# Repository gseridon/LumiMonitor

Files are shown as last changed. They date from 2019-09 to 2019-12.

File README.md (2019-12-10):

# Si7021 Temperature and Humidity Module
# Build Instructions
-----

## Author: Gino Seridon

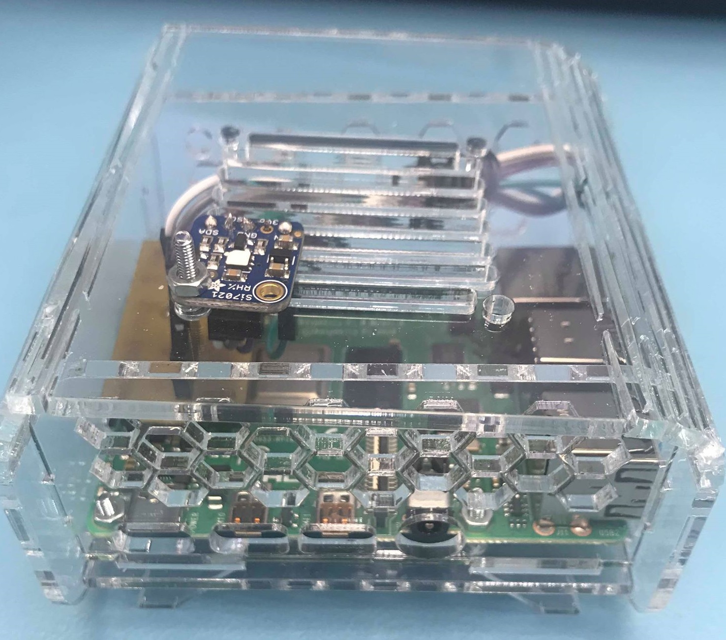
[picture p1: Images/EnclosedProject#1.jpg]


## Table of Contents
-----

1. [Introduction](https://github.com/gseridon/LumiMonitor#Introduction)
2. [Specifications](https://github.com/gseridon/LumiMonitor#Specifications)
3. [Design](https://github.com/gseridon/LumiMonitor#Design)
4. [Acquisition](https://github.com/gseridon/LumiMonitor#Acquisition)
5. [Assembly](https://github.com/gseridon/LumiMonitor#Assembly)
6. [Testing and Power Up](https://github.com/gseridon/LumiMonitor#Testing-and-Power-Up)
7. [Production Testing](https://github.com/gseridon/LumiMonitor#Production-Testing)

-----

## Introduction

-----

This readme will allow the user to build and assemble a functioning temperature and humidity reader using the si7021 sensor in conjunction with the Raspberry Pi 4.

The document will cover all points of the build, from the materials, budget and time commitment, to the mechanical assembly, testing, and power up. It will also cover all the problems that was encountered during the project, steps to take to prevent them from occurring, as well as highlighting steps that may cause problems in the future. 

While the project was completed over a 13-week semester, following this build instruction should allow the user to have an assembled and functional module within 4 hours, given that the required materials and components have already been ordered and ready to be used. 

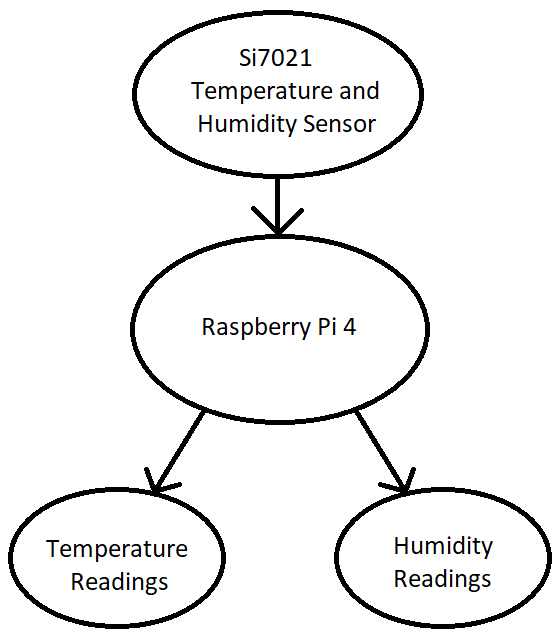
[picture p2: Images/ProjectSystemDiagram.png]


The system diagram above visualizes how the Si7021 Temperature and Humidity sensor retrieves data and interacts with the Raspberry Pi 4 to process the readings of the sensors.

-----

## Specifications

-----

A complete list of all parts, components, tools, and materials needed for this project will be listed below. Assuming that the user does not own the components, this will be the breakdown of the budget (in Canadian dollars, before shipping):

| Component | Price (CAD) |
| --- | --- |
| [Si7021 Temperature and Humidity Sensor Breakout Board](https://tinyurl.com/yybwv9qn) | $12.86 |
| [CanaKit Raspberry Pi 4 Starter Kit (4GB RAM)](https://tinyurl.com/vg57wxr) | $134.99 |
| [Printed Circuit Board (PCB)](https://www.seeedstudio.com/free-assembly-for-5-pcbs.html) | $5.21 ($3.92 USD) |
| [Clear Acrylic Casing](https://www.protocase.com/design/send-your-cad.php) | $35.00 |
| [Headers for the PCB ](https://tinyurl.com/ufy8mfr) | $21.99 |
| [Jumper Wires](https://tinyurl.com/unpvbn7) | $15.99 |
| [22 Gauge Insulated Wires](https://tinyurl.com/wlea6bo) | $18.99 |
| [Ethernet Cable](https://tinyurl.com/sbod2cs) | $8.29 |
| [Ethernet-USB Adapter](https://tinyurl.com/tccs4yx) | $20.05 |
| [Nuts and Bolts Kit](https://tinyurl.com/vyvv2pt) | $31.98 |
| **Total** | **$305.25** |

With these items, the cost will be **$305.25 + $39.70** in tax, totaling to **$344.93.** The Ethernet Cable and Ethernet-USB Adapter are optional, as the user will be able to connect their Raspberry Pi to a computer monitor if it has an HDMI port. If the monitor does not have an HDMI port, then the user must use the cable and adapter. The cost will be reduced depending on which items the user already has in possession.

The total cost of the budget will vary depending on the shipping cost, but it should be around the same price range. Considering that the Printed Circuit Board and Acrylic Casing has been obtained from Humber College, the price used for the PCB and the casing will be an accurate estimate.

The cost of shipping is not included as it can vary depending on different factors, such as the address on where the products will be shipped, the shipping method, and membership discounts/free shipping perks. 

-----

## Design

-----

The design files are important for the project, as they will dictate the appearance of the printed circuit board and the casing. The design of the printed circuit board is simplistic, as there are only four (4) pins used by the si7021 sensor and therefore the connections made from the sensor the RP4 are straightforward.

The creation and the design of the PCB is done using the free software <a href="https://fritzing.org/home/">“Fritzing.”</a> This program will provide a <a href="https://raw.githubusercontent.com/gseridon/LumiMonitor/master/Images/BreadboardV1.png">breadboard view</a> of the connections, a <a href="https://raw.githubusercontent.com/gseridon/LumiMonitor/master/Images/SchematicV1.png">schematic</a>, as well as a view of the <a href="https://raw.githubusercontent.com/gseridon/LumiMonitor/master/Images/PCBV1.png">printed circuit board</a>. There are two Fritzing files used: one to display the breadboard and the schematic, and another for the designed PCB (this will be the file used when creating the PCB).

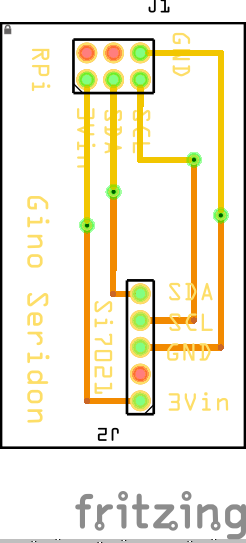
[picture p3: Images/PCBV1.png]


The design is simplistic and neat in order to reduce complications. The files can be tweaked for personal customization, but they are perfectly useable in terms of functionality. There were very little problems when designing the PCB, however, be mindful of the VIA hole size, as it may cause problems when finding a suitable size wire. Obtaining this component will be described later on in the Acquisition Section.

The enclosure is a design that was retrieved <a href="https://www.thingiverse.com/thing:3729316">online</a>. It uses cover design that allows the acrylic to bend over the raspberry pi, with several ventilation holes to help regulate the heat of the RP4.

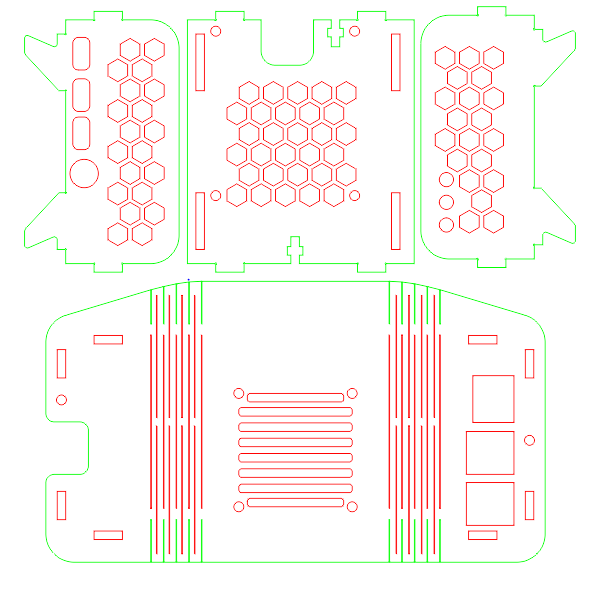
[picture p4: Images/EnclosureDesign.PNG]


The <a href="https://github.com/gseridon/LumiMonitor/blob/master/Mechanical/Raspberry_Pi_4_Model_B_Retro_Case_-_All_Parts_v2.0.cdr">design file</a> can be accessed and edited using the program “CorelDRAW”, which offers a 15-day trial for new users. 

Obtaining this component will be described in the Acquisition Section.

-----

## Acquisition

-----

The parts and components needed for this project is listed in the specification. They can be found online, and links are also provided in the specifications section. Allow a couple of days for delivery, depending on the shipping type used to deliver the parts.

Acquiring the PCB and the enclosure will require a bit more time, as they must be custom made based on the design files submitted. It takes around 4-5 business days to process the custom request and to have it delivered to a specified address. Plan ahead of time when it comes to this, as this will be the biggest cause of delays should there be problems down the line, especially when getting it replaced.

**The Printed Circuit Board**
-----

The PCB design will be sent to Seeedstudio, a company that can manufacture circuit boards. The company requests that the Gerber Files of the project be sent as ZIP or RAR files in order to proceed with the PCB manufacturing. 

To create an order with <a href="https://www.seeedstudio.com/free-assembly-for-5-pcbs.html">Seeedstudio</a>:

\-   Open the <a href="https://github.com/gseridon/LumiMonitor/blob/master/Electronics/GinoSeridon_TemperatureHumiditySensorWithoutPiV2.fzz">PCB Design File</a> in Fritzing

\-   Export the file as an Extended Gerber 

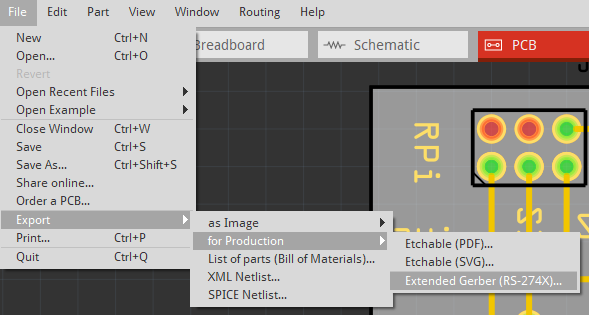
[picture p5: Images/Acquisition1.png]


\-   Select a folder to export the files into

\-   Compress the folder into a ZIP or RAR file

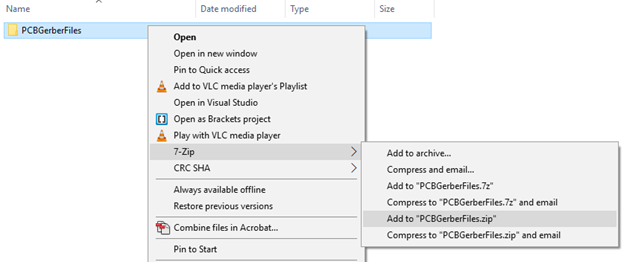
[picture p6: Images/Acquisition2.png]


\-   File is created

\-   Upload this newly created ZIP or RAR file on the Seeedstudio website and follow the steps online.

Note that if some of the PCB specifications are changed, the price will also change accordingly. The site will provide an estimate on how long it will take for the PCB to be manufactured and when it will arrive.

**The Enclosure**
-----

The enclosure design will be sent to Protocase, a company that can manufacture cases and enclosures, among other services. To request for a custom design enclosure, we must export the CorelDRAW file as a .dwg file. This file is uploaded into the repository and it will be used to place the order for the enclosure.

To order from Protocase:

\-   Access the website’s <a href="https://www.protocase.com/design/send-your-cad.php">page</a> for custom enclosure orders

\-   Send the design by selecting “Upload your file using request a quote form”

\-   Select “I have 3D CAD file(s) to upload”

\-   Upload the .dwg file

\-   Select “Part(s) or Enclosure(s) from other materials” for the type of enclosure

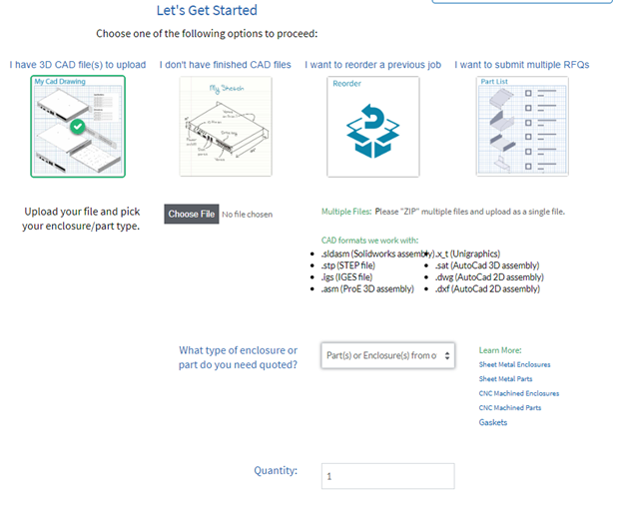
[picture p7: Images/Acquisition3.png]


\-   Select the Material type as “Acrylic”, with a thickness of “ 0.118’’ | 3.0mm”

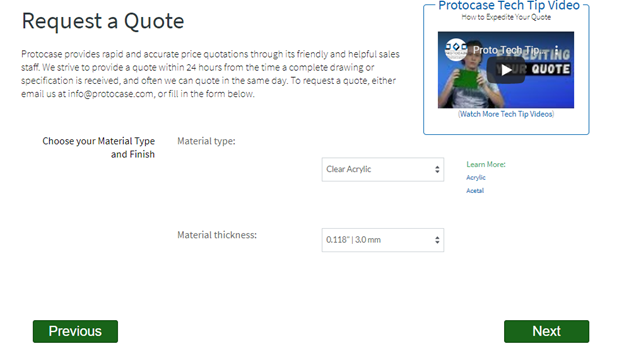
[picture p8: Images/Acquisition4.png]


\-   Fill out the rest of the form with personal information and submit

\-   Wait for an email from Protocase; this will contain the quote on the enclosure

\-   Follow the email and steps for ordering the case.

Awaiting the PCB and the enclosure will take around a week, so keep that in mind when setting deadlines.

**Tools and Software**
-----

Lastly, on top of the parts, components, and materials needed for the project, there are also some tools required to setup and assemble the project. These tools include:

\-   Windows PC

\-   computer monitor (preferably with an HDMI port; if not, then an Ethernet cable and Ethernet-USB adapter is required)

\-   computer mouse

\-   computer keyboard

\-   ohmmeter

\-   solder iron and lead

\-   wire stripper

\-   wire cutter

\-   breadboard

\-   Phillips Screwdriver

Software programs needed include:

\-   <a href="https://fritzing.org/home/">Fritzing</a>

\-   <a href="https://www.coreldraw.com/en/pages/ppc/coreldraw/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">CorelDRAW</a>

\-   <a href="https://www.balena.io/etcher/">balenaEtcher</a>

-----

## Assembly

-----

Once the components, tools, and materials have been acquired, the project can be assembled.

**Installing Raspbian onto the Rasberry Pi 4:**
-----

The Raspberry Pi must first be setup. On a running Windows Computer, download “Raspbian Buster with desktop and recommended software” from the <a href=” https://www.raspberrypi.org/downloads/raspbian/”>Raspberry Pi Website</a>. When that has completed, insert the microSD card into the USB reader (both from the Raspberry Pi Starter Kit) and then plug it in a USB port on the computer.

Launch balenaEtcher to mount the Raspbian into the microSD card. In balenaEtcher, select Raspbian as the Image, select the USB reader as the drive, and then click “Flash!” Wait for the Flashing and Validating to finish, and then safely eject the USB reader and leave it aside for the meantime.

Proceed by connecting the Raspberry Pi 4 to a mouse to its USB port, a keyboard to the other USB port, and its power supply to the microUSB port. The RP4 comes with its own HDMI cable, and it will be connect to the Pi’s HDMI port to a monitor’s HDMI port.

Place the microSD card in the microSD reader of the Raspberry Pi 4, then power up the Raspberry Pi using the power supply’s power button. The Operating System that was Flashed into the microSD card will automatically be installed on to the new Raspberry Pi. Follow the setup instructions that appear on the screen (and remember any password changes that are made), and the Raspberry Pi will be ready for future use. This section should not take more than half an hour, depending on download speed and processing speed.

**Si7021 Sensor/Header Soldering:**
-----

The Si7021 Temperature and Humidity Sensor should come with its own header. Since the header will not fit on the breakout board initially, use wire cutter so that there will only be 5 pins left on the header. The header will fit perfectly on the board, and the pins should then be soldered. Soldering the 3V pin is optional, as it will not be used. This should take no more than 10 minutes.

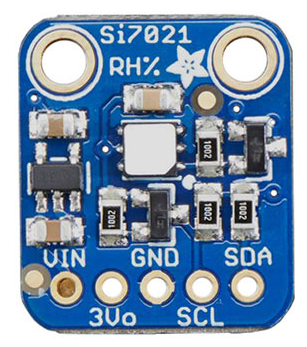
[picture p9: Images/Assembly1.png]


**Soldering Headers and VIAs on the Printed Circuit Board:**
-----

Headers must be soldered on the printed circuit board in order to connect the raspberry pi and the sensor to it. There will be two headers needed for this: 1x5 header, and 2x3 header.

First, the 1x5 header will be soldered first. This header will be placed on the topside of the PCB, with the pins being soldered at the bottom side (for reference, the student name and pin names will be on the topside of the PCB). When the header is placed on the topside, turn over the PCB and proceed with soldering the pins to the board. Ensure that the solders are clean and that they do not make contact with other pins on the board. The pins to be soldered are GND, SCL, SDA, and 3vin (the labels can be found on the topside of the PCB); the lone pin without any connections does not need to be soldered.

The second header will then be soldered afterwards. This header will be placed on the bottom side of the PCB, with the pins being solder at the topside of the board. Place the header on the bottom side of the PCB, then turn over the PCB to proceed with soldering the pins. There will be two pins that do not need to be soldered, and it will be the two pins that do not have any connections or labels attached to them. The four pins that will be soldered are the GND, SCL, SDA, and 3Vin.

Finally, when both headers are soldered to the board, the VIAs will be soldered using the 22 gauge insulated wires (these will be thin enough that they will be able to fit through the VIAs). Use the wire stripper to remove the insulation, and fit the wire through the VIA. One end of the wire will be soldered, ensuring that the solder is making contact with the copper wiring on the board. After one end is finished, cut the other end of the wire on the opposite end of the soldered VIA. The remaining insulation is removed from the wire, and then the wire end is soldered to the copper around the VIA. The end result should look like a wire soldered on both ends that is passing through the VIA. Proceed to do these steps until all 4 of the VIAs are connected.

Try to make sure that the solder points are done quickly and neatly. If soldered for too long, some areas of the board may overheat and become unusable, which may cause problems down the line. Do not use too much solder, as it may melt over to neighbouring wires, causing a short in the circuit. Do not rush soldering, but it should not take longer than an hour for this section.

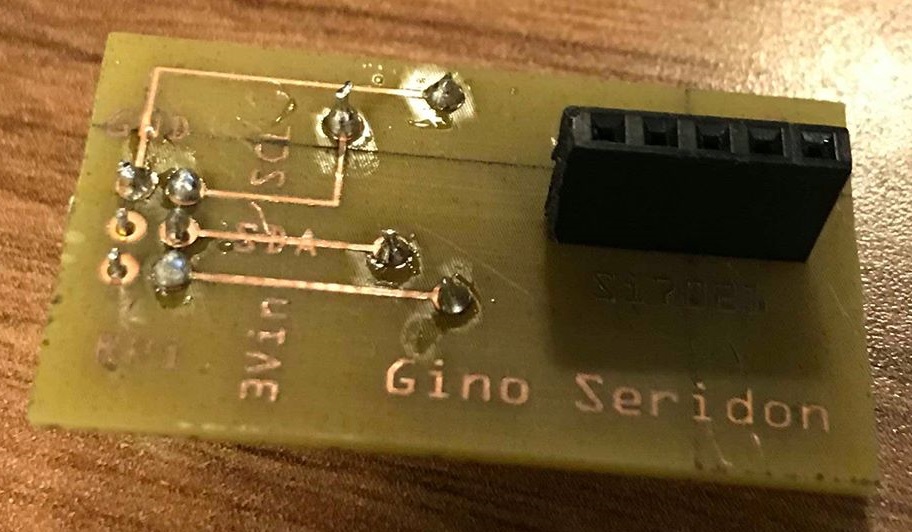
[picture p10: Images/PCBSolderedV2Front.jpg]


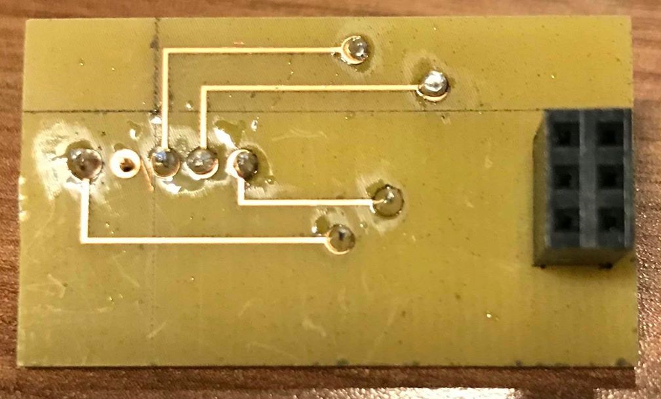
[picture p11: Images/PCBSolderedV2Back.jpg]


**Assembling the Enclosure with the Raspberry Pi:**
-----

**Note: Due to the nature of the enclosure, it is highly recommended that the Raspberry Pi 4, the Printed Circuit Board, and the Si7021 Temperature and Humidity Sensor are all configured, tested, and are fully functional before assembling them with the enclosure.

The enclosure is comprised of four pieces, the two side pieces, the bottom piece, and the large, overhead piece. Start by placing the raspberry pi on the bottom piece, aligning the case’s mounting holes with the Raspberry Pi’s. Secure the raspberry pi to the bottom piece using nuts and bolts.

Based on the orientation of the Raspberry Pi, the two side pieces of the enclosure should be attached to the bottom enclosure piece with accordance to the Raspberry Pi’s ports (one of the side pieces will have holes for the RP4’s ports, while the other does not). Use this knowledge to determine which side piece will fit with the bottom enclosure piece.

Attach the printed circuit board to the raspberry pi’s pins (the first 6 pins at the top of the pi, as seen on the breadboard connection), as well as four jumper wires on the proper pins of the circuit board (one for GND, SCL, SDA, and 3Vin).

Closing the case using the overhead piece is the trickiest part of using this case. Start on the end with the microSD card reader of the RP4. Fit the top piece of the enclosure to the bottom piece where the microSD card hole will be, and then use a single nut and bolt to hold and secure the two pieces together.

Slip the four jumper wires through the top slit near a mounting hole of the overhead piece. Connect these four jumper wires to the Si7021 sensor while keeping in mind the proper GND, SCL, SDA, and 3Vin pins. When the wires are connected, move the sensor so that it is resting on top of the case, and the breakout board’s mounting hole aligns with the mounting hole on the case. Use a nut and bolt to secure the sensor’s position. Afterwards, carefully bend the casing until it encloses the entire raspberry pi, and that it will connect to the bottom case piece on the other side. This side will also have another mounting hole to hold the case in its place using a nut and bolt. This part should take around half an hour, assuming the user takes their time and handles the components with care.

**The final result:**

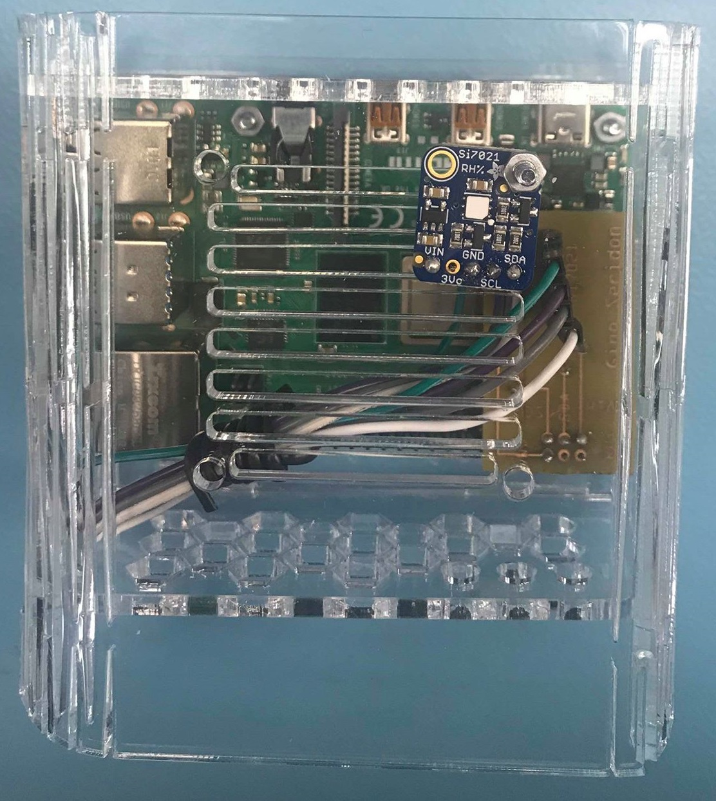
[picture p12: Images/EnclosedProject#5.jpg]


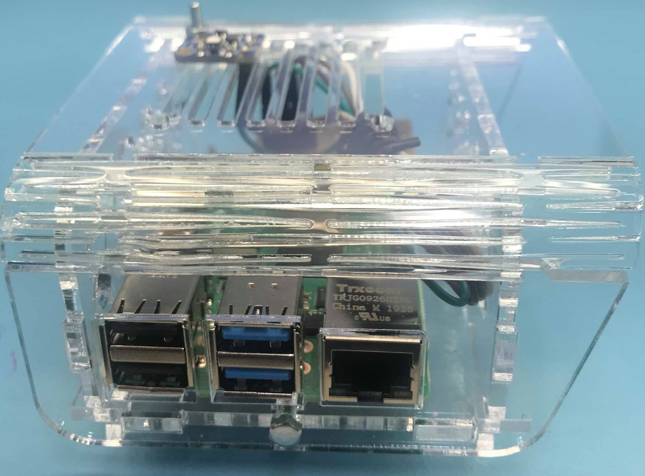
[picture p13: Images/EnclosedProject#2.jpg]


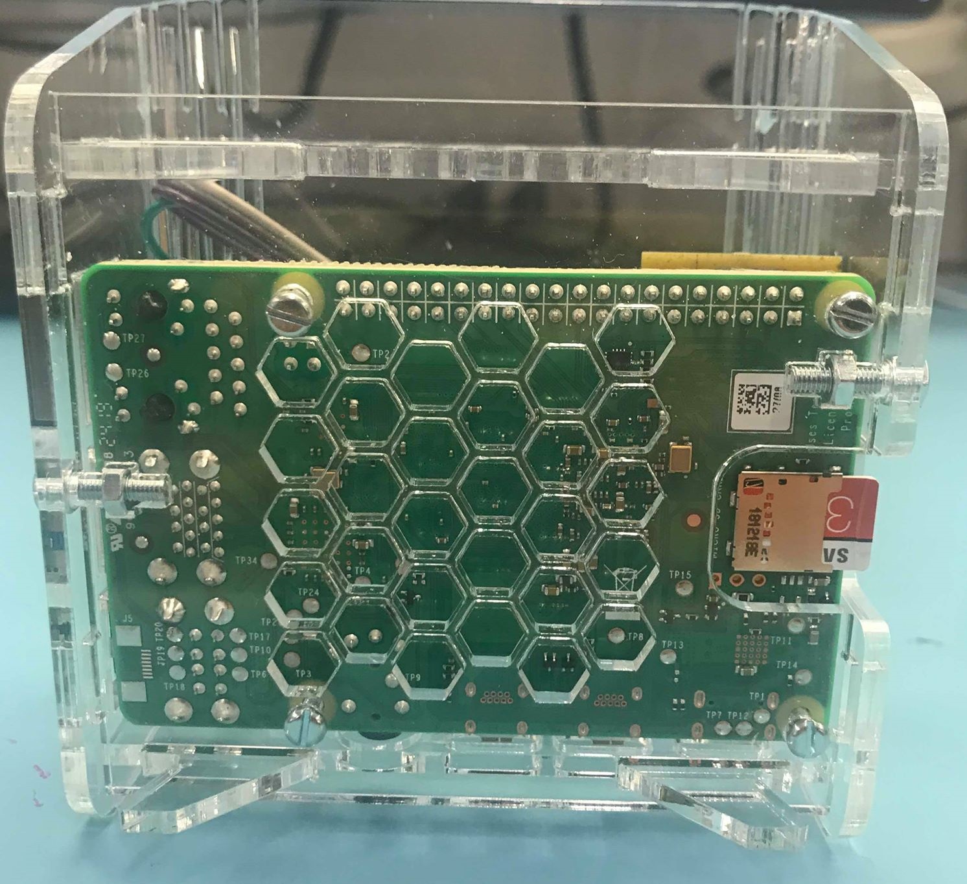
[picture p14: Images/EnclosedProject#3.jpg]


-----

## Testing and Power Up

-----

**Note: Due to the nature of the enclosure, it is highly recommended that the Raspberry Pi 4, the Printed Circuit Board, and the Si7021 Temperature and Humidity Sensor are all configured, tested, and are fully functional before assembling them with the enclosure.

Before testing the Raspberry Pi, the sensor and printed circuit board must be tested. It is simple enough to test: the soldered connections will be tested using an ohmmeter and some jumper wires. The sensor and printed circuit board can be plugged in a breadboard to make the connections clearer and easier to trace. Connect the PCB and sensor to the proper pins using jumper wires, connect it to a power supply, and then measure the resistance in the circuit. If the ohmmeter is reading an infinite resistance, it means that there is no electrical current flowing through the circuit that is being measured. If this is the case, look over the soldered pins and VIAs and ensure that the soldered points appear like a sloping hill, or a "Hershey Kiss".

Once it is verified that the PCB and sensor are soldered properly, the next step is to ensure that the Raspberry Pi is up to date with its libraries. Use the following commands from the command line to update the raspberry pi:

```
sudo apt-get install upgrade

sudo apt-get install update

sudo apt-get install i2c-tools
```

Once that’s done, run this command to install the Adafruit library:

```
sudo pip3 install adafruit-circuitpython-si7021
```
 
Then we need to enable the I2C bus on the Pi.

\-   Run sudo raspi-config

\-   Select Interfacing Options

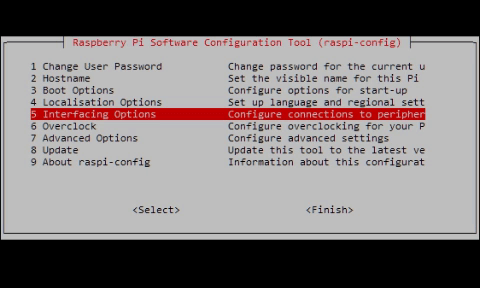
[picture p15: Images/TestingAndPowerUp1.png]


\-   Select P4 SPI

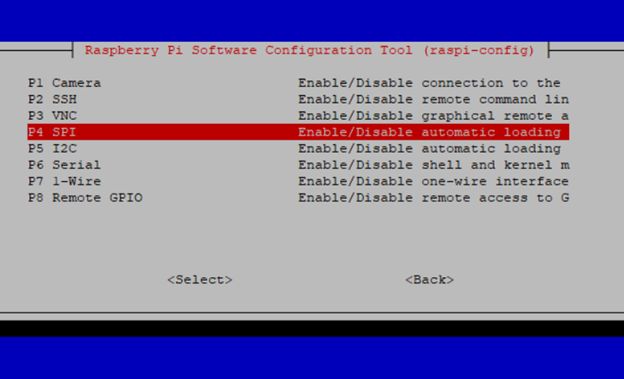
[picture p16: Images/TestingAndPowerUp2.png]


\-   Select Yes when prompted to enable SPI and when asked about automatically loading the kernel module

\-   Select Finish and confirm that the system will reboot

To test the sensor, attach the printed circuit board to the raspberry pi’s pins (the first 6 pins at the top of the pi, as seen on the breadboard connection), as well as four jumper wires on the proper pins of the circuit board (one for GND, SCL, SDA, and 3Vin). Connect these four jumper wires to the Si7021 sensor while keeping in mind the proper GND, SCL, SDA, and 3Vin pins.

Run this command on the command line:

```
sudo i2cdetect -y 1
```

This will display the open address being used and will display a hexadecimal value representing the module. If the si7021 sensor is being detected properly the address that you will see will be 40.

After confirming that the sensor is being detected, write the code for the sensor. To create the file, type in the command line:

```
nano si7021_test_code.py
```

“si7021_test_code.py” is the file name. Write in the code in this file (this code is also uploaded in the <a href="https://github.com/gseridon/LumiMonitor/blob/master/Software/si7021_test_code.py">repository</a>):

```
import time
import board
import busio
import adafruit_si7021

# Create library object using our Bus I2C port
i2c = busio.I2C(board.SCL, board.SDA)
sensor = adafruit_si7021.SI7021(i2c)

while True:
    print("\nTemperature: %0.1f C" % sensor.temperature)
    print("Humidity: %0.1f %%" % sensor.relative_humidity)
    time.sleep(2)
```

To run this file, either find the file in the Pi’s directory and run the program using Python, or type in a command in the terminal:

```
python ./si7021_test_code.py
```

If all is working well, the sensor should be actively reading the temperature and humidity of its surroundings and updating these values every second on the screen.

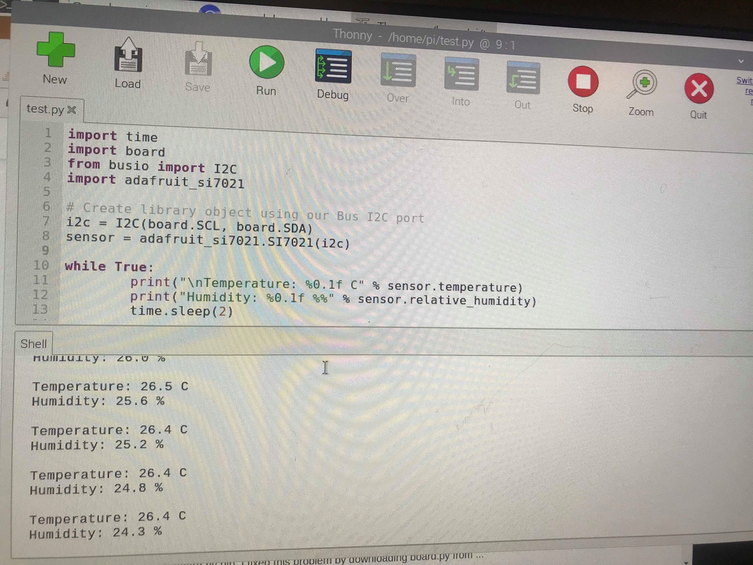
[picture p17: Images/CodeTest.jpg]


This whole section should take around an hour, with variance depending on the speed of download.

-----

## Production Testing

-----

Based on the components alone, this project is realistically not viable for mass production due to the sheer price of the Raspberry Pi 4. The project can be done using an Arduino, which costs less than the Raspberry Pi, however the steps that will be taken to create a functional project may be vastly different compared to what was explained in this build.

Assuming that the Raspberry Pi 4 will be used for production testing, the actual testing for the components will be relatively simple. The PCBs will be mass soldered and will be tested for connectivity at the end of the production line using a simple resistance test. The main testing procedure for the sensor would be to connect it to a tester Raspberry Pi and attempting to detect the sensor through the I2C command. If the sensor’s address does not show, it will be sent to a reject pile to be checked for quality.

The case may need to be changed for mass production due to the delicate nature of the enclosure; breakage may occur more often without the constant supervision of human workers. Changing the enclosure to a case that can easily be assembled would be the better alternative.

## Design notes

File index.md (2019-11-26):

<b>Entry12: 11/26/2019</b>

The presentation is due today. The powerpoint file has been uploaded into the repository and can be found <a href="https://github.com/gseridon/LumiMonitor/blob/master/Documentation/HardwarePresentation.pptx">here</a>.

<b>Entry11: 11/22/2019</b>

Finishing up the documentation of the project. I have updated the <a href="https://github.com/gseridon/LumiMonitor/blob/master/Documentation/Project%20Budget.pdf">final budget</a> of the project along with the associated <a href="https://github.com/gseridon/LumiMonitor/blob/master/Images/AmazonOrder2.png">receipts</a>. Unfortunately, I was not able to get a refund on the initial Raspberry Pi 3 purchase, so that is a cost that I will absorb. Financially, it has cost me a total of $247.96CAD, compared to the initial figure of $81.89CAD.

I am on track of my schedule, despite falling behind during the middle of the project. Currently preparing for my presentation on November 25. Afterwards, I will be working on the build order of my project.

<b>Entry10: 11/19/2019</b>

I have worked on finding an enclosure for my project this week to encase the RP4, PCB, and sensor. I have found a suitable case <a href="https://www.thingiverse.com/thing:3729316">online</a> and printed it in the prototype lab. I have uploaded the <a href="https://github.com/gseridon/LumiMonitor/blob/master/Mechanical/Raspberry_Pi_4_Model_B_Retro_Case_-_All_Parts_v2.0.cdr">CorelDraw .cdr File</a> in the project repository; this is the enclosure design:



The design allows for the raspberry pi ports to have an opening, allows for easy access to the SD card slot, and plently of holes in the design to properly ventilate the project. I went to the prototype lab to have the design cut with assistance from Professor Kelly Gray.

After laser-cutting the design, I initially intended the sensor to be attached to the PCB, to remove unnecessary wiring. However, after testing the sensor in the enclosure, I have found that when the raspberry pi heats up, it affects the temperature readings of the sensor. Even with all the ventilation holes, the sensor would still be too close to the raspberry pi. Ultimately, I have decided to move the sensor outside of the case, connected to the PCB through wires, and the sensor is secured onto the case using a screw. With the sensor being outside of the case, it will no longer be affected by the heating hardware and it will be more able to accurately measure the temperature and humidity of the surroundings. Here are some photos of the finished, assembled design:







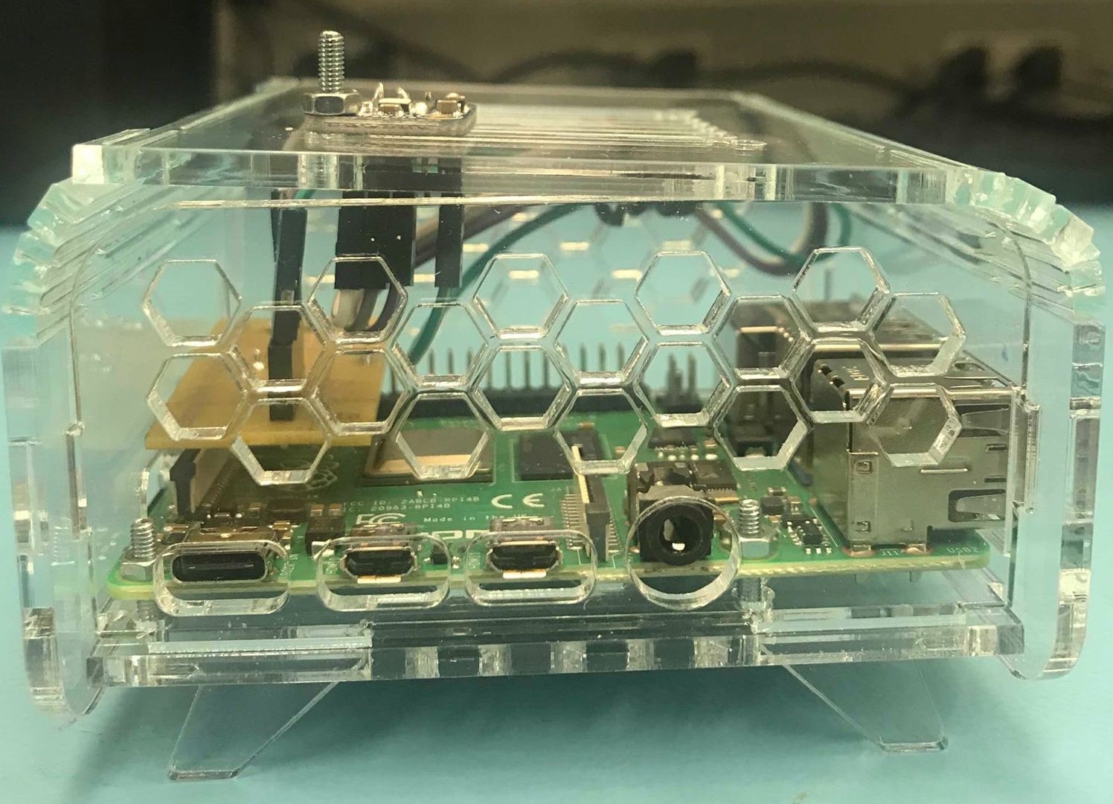
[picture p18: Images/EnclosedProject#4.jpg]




<b>Entry09: 11/08/2019</b>

I have completely remade the PCB because it was not correctly soldered the headers and it was not powering up properly with the pi, hence I was not able to do an in class demo. I have uploaded an updated version of the <a href="https://github.com/gseridon/LumiMonitor/blob/master/Electronics/GinoSeridon_TemperatureHumiditySensorWithoutPiV2.fzz">Fritzing File</a> for this new PCB; the main change that I have made is a bigger via and thinner wires. The headers are then soldered in the proper position and can now be mounted directly onto the raspberry pi. Here is the new soldered PCB views (frontside and backside):





The PCB fits nicely on top of the raspberry pi now and is directly connected, removing the need for wires:

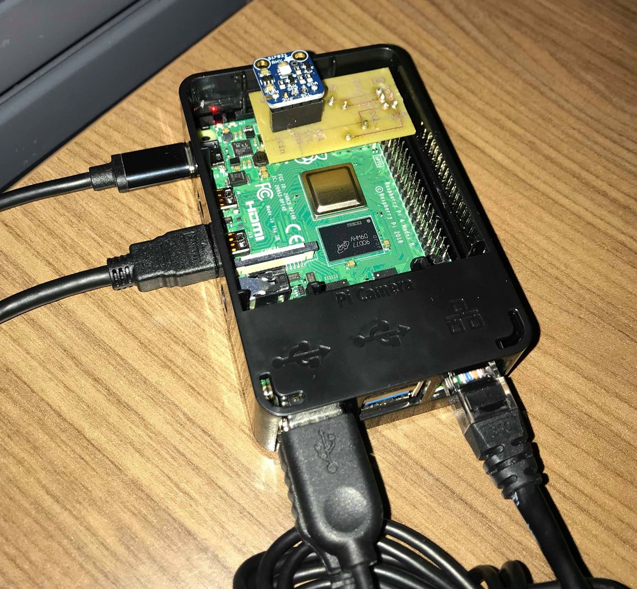
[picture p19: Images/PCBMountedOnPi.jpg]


I have also uploaded a video demo <a href="https://github.com/gseridon/LumiMonitor/blob/master/Images/PCBPoweredUpDemo.mp4">here</a> to demonstrate that the pi is receiving information from the sensor through the soldered PCB.

Financial status is the same as last week; the refund is currently being processed and Amazon will inform me of any updates.

Moving forward, I am currently working on the design for the casing of the raspberry pi. Since the PCB is mounted directly on the pi, I would need to design a case for the RP4 with an opening at the top to allow the sensor to evaluate the temperature and humidity. I will be getting this design printed by next week Monday.

<b>Entry08: 11/08/2019</b>

As of today, I have caught up with my project schedule. I have received my newly purchased Raspberry Pi 4 on Sunday, November 3rd and have had no problems setting up the operating system and additional upgrades for the coding environment. I have been able to properly assemble my breadboard with the si7021 temperature/humidity sensor and connected them both to the RP4 (as shown below), marking my breadboard milestone for this project.

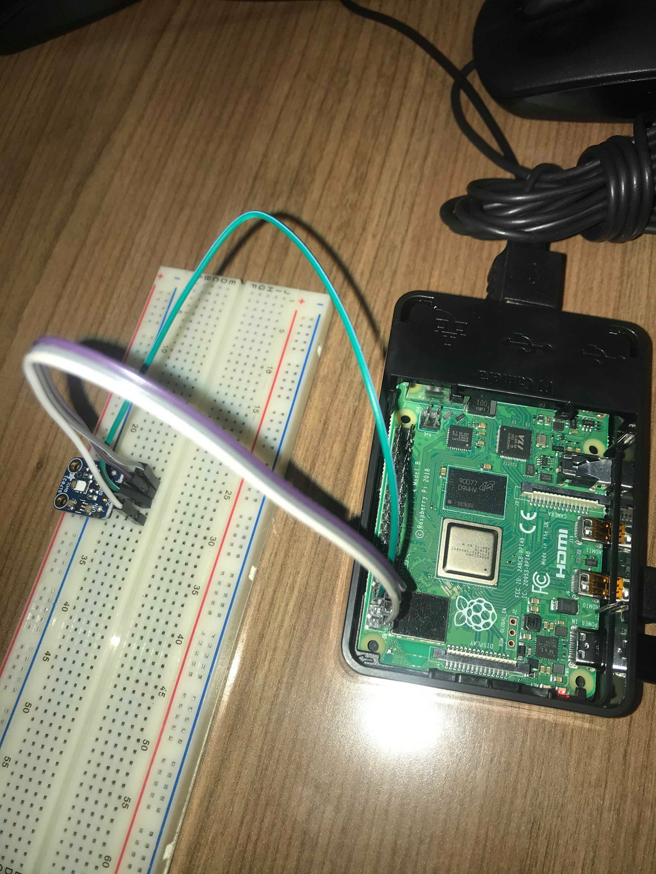
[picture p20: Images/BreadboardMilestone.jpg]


The <a href="https://github.com/gseridon/LumiMonitor/blob/master/Software/si7021_test_code.py">code</a> that I am using from adafruit works properly with the RP4 and sensor, and it is displaying the proper temperature and humidity readings from the sensor.



I have picked up my Printed Circuit Board a couple of weeks ago after submitting my design to the prototype lab, and I have soldered it with headers to allow wires to connect to the board:

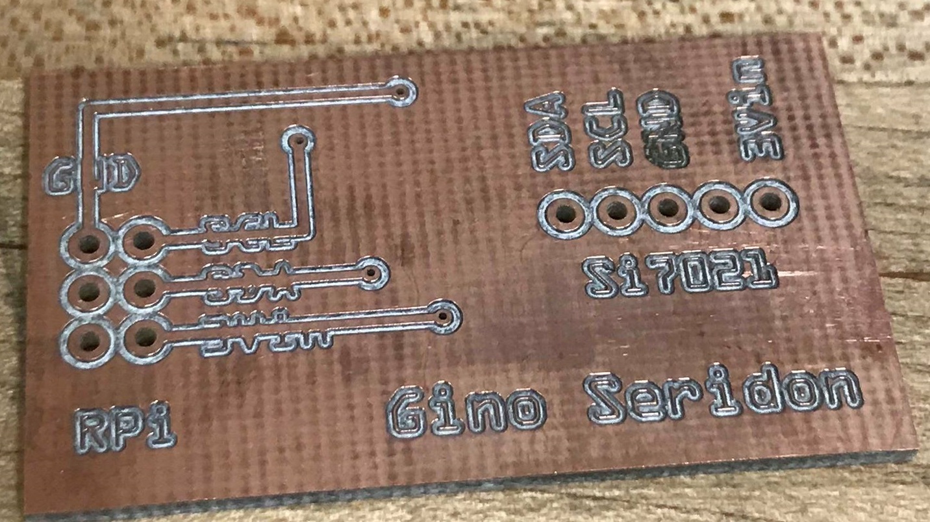
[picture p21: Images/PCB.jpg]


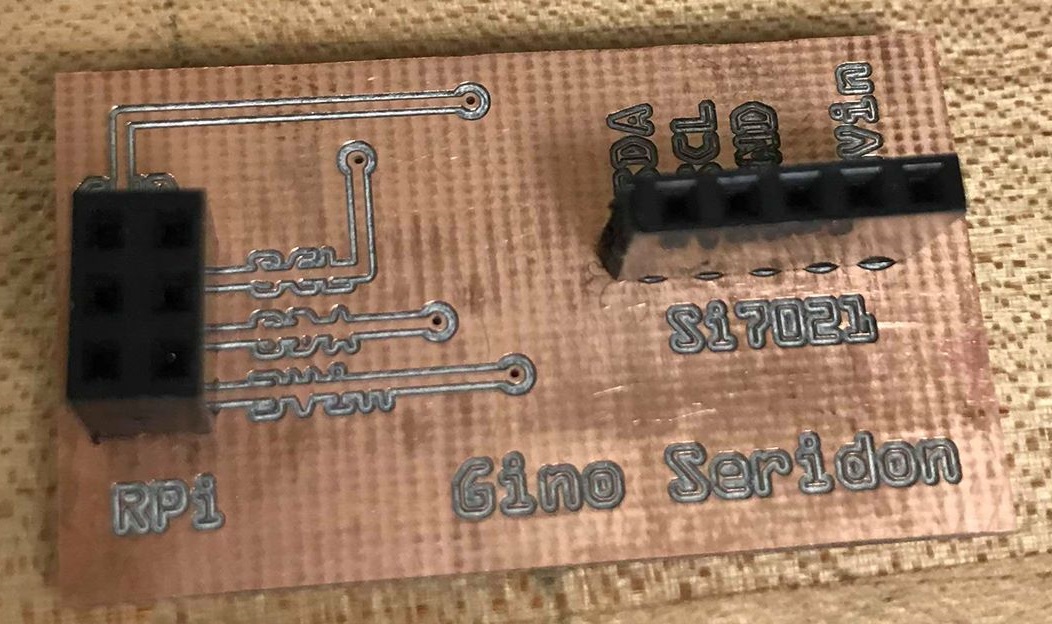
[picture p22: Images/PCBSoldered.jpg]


To test the circuit of the sensor, breadboard, and PCB, I have connected them to a voltmeter to verify the correct voltage. Recall that this sensor uses 3 VDC. The image below shows that the correct voltage of ~3V is being shown when the RP4 is connected to the sensor via breadboard:

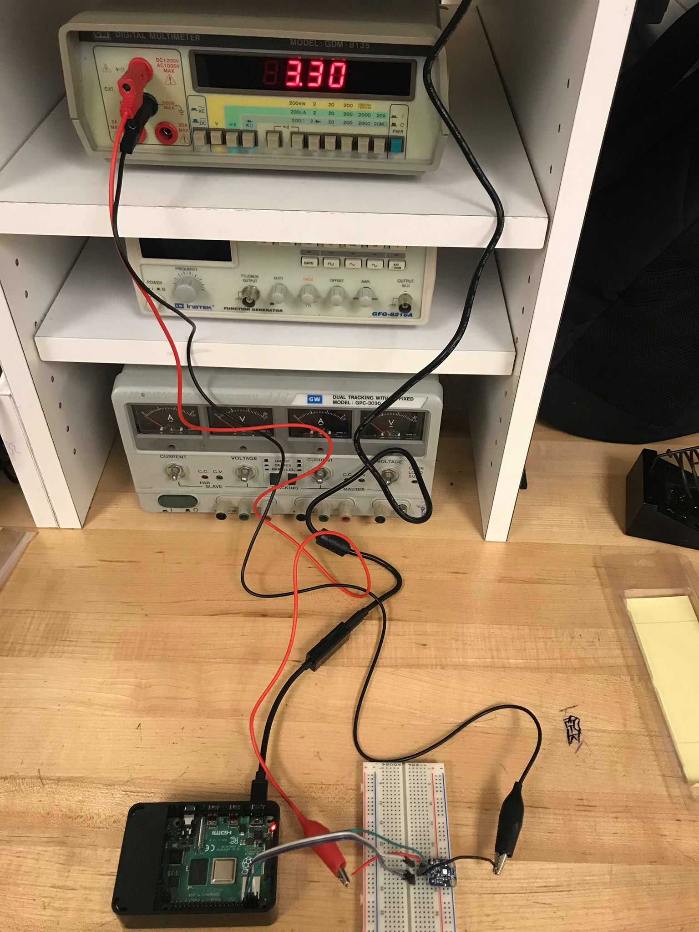
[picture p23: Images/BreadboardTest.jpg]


The image below shows that the correct voltage of ~3V is being shown when the RP4 is connected to the sensor via PCB (and using the breadboard as a way to connect the voltmeter):

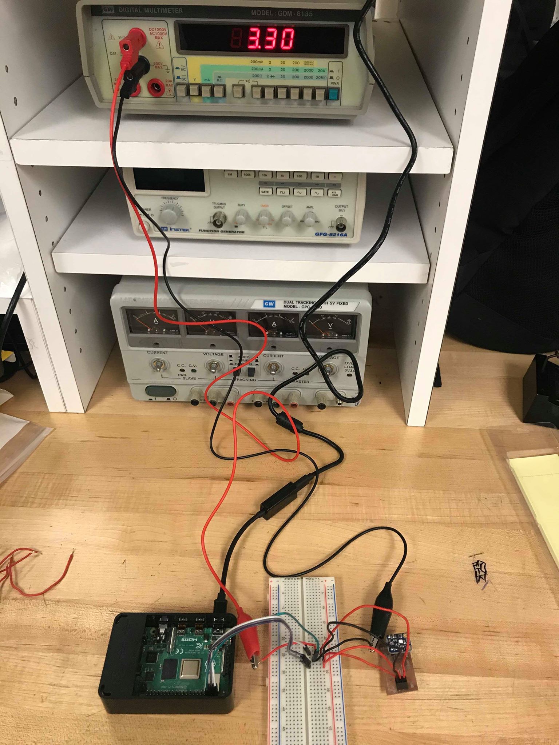
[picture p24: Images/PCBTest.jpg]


With these being completed, I am officially on schedule for next week, despite being set back over two weeks due to complications with the raspberry pi.

Financially, I have spent over three times the amount that I initially started with. My initial purchase consisted of $81.89CAD, but with complications with the Raspberry Pi 3 and burning of SD cards, I have spent an additional $166.07CAD in the past week, bringing the total cost to $247.96CAD. I am still in the process of trying to get a refund on the RP3 that I have initially purchase, which could bring down the amount spent below $200. I will post updates on this situation when the refund goes through.

The only other problem that I have encountered after receiving the RP4 is that I cannot seem to connect the pi to my home internet network. This severely limited the amount of time that I have been able to work on this project, needing to contantly travel on campus after class hours to work on. However, despite all the complications and headaches, I'm right on schedule for the following week.

<b>Entry07: 11/01/2019</b>

I'm having a lot of problems with the Raspberry Pi at the moment, and it is severely delaying my progress with the course.
I have set up an OS for the pi during the break, but the pi heats up extremely quickly within the first few minutes of being powered up. The microSD card that I was using for the pi burned out a few days ago as well. This pressured me to purchase another SD card last minute, which did not arrive until Wednesday of this week. This new SD card was also uploaded with the operating system, which the balenaEtcher is verifying to be acceptable to use. However, when I try to install the operating system now, the raspberry pi would still heat up very quickly, and it would show an error on the screen. I have tried several times to reupload the operating system into the SD card, each time the disk imager would verify that the loading was successful (I even used a different SD card from a friend on different attempts). But the same thing occurs, the raspberry pi would continuously show an error and stopping me from installing the operating system, thus halting my progress on the assignment.

I'm considering on just purchasing the new Raspberry Pi 4, as I suspect that the Raspberry Pi 3 that I have purchase is faulty and corrupting the SD cards that I use for it. I will be purchasing the Raspberry Pi 4 this weekend and hope that it will arrive quickly, so that I can set up operating system once more and run the code for the si7021 temperature/humidity sensor.

Financial wise, things have taken a turn for the worse. While I will be attempting to refund the Raspberry Pi 3, I have purchased a micro SD card in the process of troubleshooting my problems with the Pi. I will also be looking to purchase the complete set of the Raspberry Pi 4 for this weekend in hopes that I will be able to catch up with my schedule.

This week's purchases:
- MicroSD card: $11.97 CAD + $1.56, free shipping
- Raspberry Pi 4: $134.99 CAD + $17.55 tax, free shipping

Schedule-wise, I am a behind on loading the operating system and the breadboard milestone, as I have not been able to get the RP3 to work properly. This puts me approximately two weeks behind schedule. However, if I should get the new RP4 by this weekend, I will be attempting to catch up on installing the OS and connecting the sensor to the breadboard by next week. If all goes well, I will be able to get back on schedule.

I have found the code for the si7021 temperature/humidity sensor as well, and will be attempting to use this code to test the sensor when the RP4 has arrived and set up properly.
It is uploaded <a href="https://github.com/gseridon/LumiMonitor/blob/master/Software/si7021_test_code.py">here</a>.

<b>Entry06: 10/15/2019</b>

  The schematic of the sensor and raspberry pi:
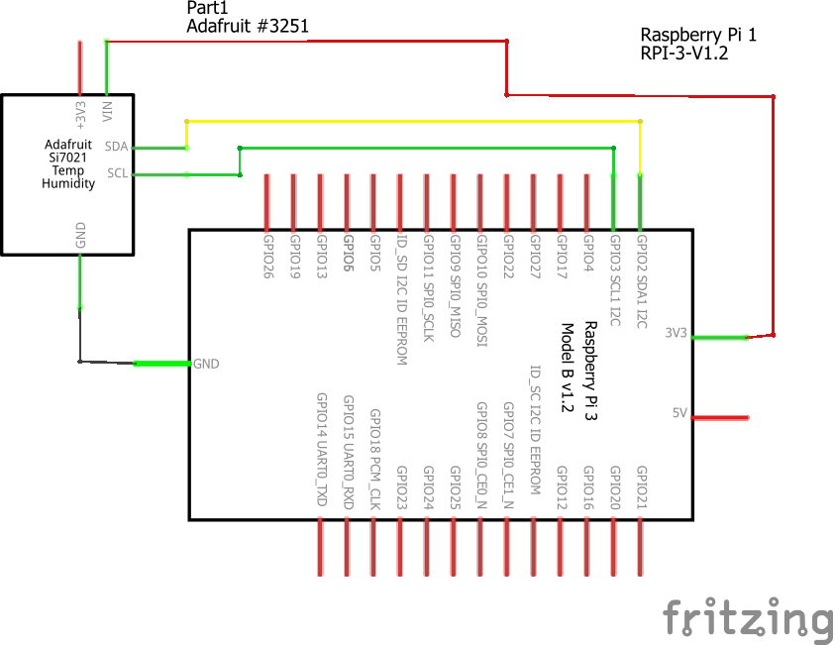
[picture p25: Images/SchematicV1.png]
  
  
  The breadboard connection: 
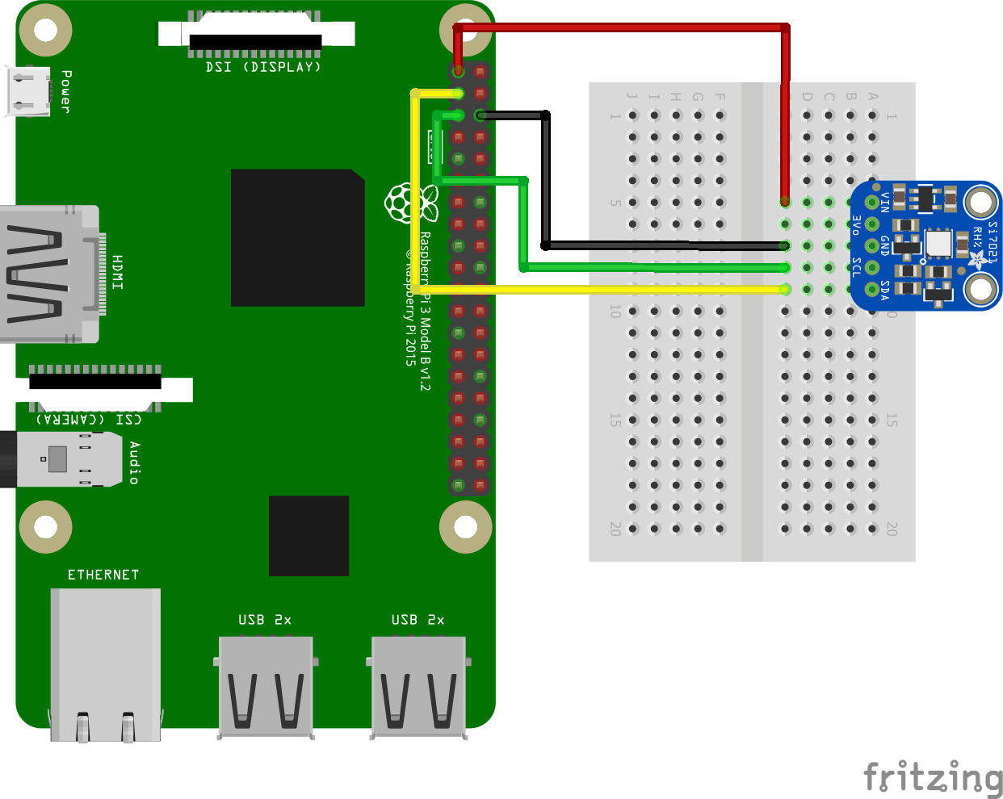
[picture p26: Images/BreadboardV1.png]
  
  
  The PCB design:
  
  

The design of the board was fairly simple. Vin is the power pin, and it is connected to the 3 VDC pin on the raspberry pi.  The sensor's 3v3 pin is not used. The GND pin is the common ground for the power and logic.  The SCL pin is the I2C clock pin, which is connected to the raspberry pi's I2C clock line. The SDA pin is the I2C data pin, which is connected to the raspberry pi's I2C data line. These pins are represented by headers instead of the actual sensor/raspberry pi; the 5 pin header is for the temperature/humidity sensor, while the 6 pin header is for the raspberry pi.

As of today, I am right on time according to my schedule. I have the breadboard, schematic, and PCB designed, and it is ready to be printed. I will be sending the gerber files to the prototype lab to have my PCB created.  I had a few problems with my initial design of the PCB, but after attending the class session and getting some feedback from Professor Medri, I was able to correctly redesign my PCB.
 
Over this past weekend, I had to re-order my Raspberry Pi as the parcel has been lost in the mail and could not be retrieved. Amazon was able to resend my purchase, and I have acquired the Raspberry Pi and the sensor by Sunday, October 13. There were no additional charges to this transaction, so I am on track with my financial status.  All the images (schematic, PCB, breadboard) and files (FZZ file using the pi and without it) regarding the hardware of the project has been uploaded into my repository, with the appropriate links in the blog post:
  
  <a href="https://github.com/gseridon/LumiMonitor/blob/master/Images/SchematicV1.png">Schematic</a>, 
  <a href="https://github.com/gseridon/LumiMonitor/blob/master/Images/BreadboardV1.png">Breadboard</a>,
  <a href="https://github.com/gseridon/LumiMonitor/blob/master/Images/PCBV1.png">PCB</a>

  The two fritzing files; one with the raspberry pi, and one without it (just for the PCB design):
  <a href="https://github.com/gseridon/LumiMonitor/blob/master/Electronics/GinoSeridon_TemperatureHumiditySensorV1.fzz">With Pi</a>,
  <a href="https://github.com/gseridon/LumiMonitor/blob/master/Electronics/GinoSeridon_TemperatureHumiditySensorWithoutPiV1.fzz">Without Pi</a>

<b>Entry05: 09/29/2019</b>

  I have placed my order for the Raspberry Pi, the webcam, and the temperature sensor. I have also updated the project budget to include the additional purchase of the Raspberry Pi.

Proof of Purchase: <a href="https://github.com/gseridon/LumiMonitor/blob/master/Images/AmazonOrder.png">Amazon</a>, 
<a href="https://github.com/gseridon/LumiMonitor/blob/master/Images/DigikeyOrder.png">Digikey</a>

<b>Entry04: 09/24/2019</b>

  Today my group members and I had our meeting with our collaborator, running our ideas through him and getting some feedback from him. He was very enthusiastic towards our ideas and offers his full support to the direction of our project.
  
  I have uploaded the project budget for the LumiMonitor's temperature sensor, with the webcam price included.
  
  Link: <a href="https://github.com/gseridon/LumiMonitor/blob/master/Documentation/Project%20Budget.pdf">Project Budget PFD</a>

<b>Entry03: 09/10/2019</b>

  Submission of the hard copy printout of the project proposal. I have completed a project schedule in the form of a gantt chart and have converted it into a PDF. This version of the schedule is uploaded into the repository and can be found <a href="https://github.com/gseridon/LumiMonitor/blob/master/Documentation/LumiMonitorScheduleGanttChart.pdf">here.</a> 
  
  This schedule is based off the due dates outlined in the <a href="https://six0four.github.io/ceng317/">CENG317 Course Repository.</a>

<b>Entry02: 09/09/2019</b>

  Completed the proposal content and the project proposal, and converted them into a PDF file. These files, along with the Excel  proposal sheet, are uploaded to my online repository, in the "Documentation" folder. I have also completed creating all the different folders needed in the repository today, leaving a note in each folder to dictate the folder's future content.
  
  The links for the uploaded documents are as follows:
  - <a href="https://github.com/gseridon/LumiMonitor/blob/master/Documentation/ProjectProposalGinoSeridonLumi.pdf">Project Proposal (PDF)</a>
  - <a href="https://github.com/gseridon/LumiMonitor/blob/master/Documentation/ProposalContentGinoSeridonLumi.pdf">Proposal Content (PDF)</a>

  Lastly, I have activated the github master branch for the repository, enabling me to publish the repository website.
  
  Link: <a href="https://gseridon.github.io/LumiMonitor">https://gseridon.github.io/LumiMonitor</a>

<b>Entry01: 09/05/2019</b>

  First day working on the Lumi Monitor project. I did a bit of research for the project to try and brainstorm some ideas for it. I have created a repository today, as well as having completed my registration along with my group members on Riipen. I'm filling out the proposal with content pretaining to the Lumi monitor and will be uploading the finished documents on github.

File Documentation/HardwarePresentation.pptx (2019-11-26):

## Temperature/Humidity Sensor - si70210

Gino Seridon

## Proposal

- Sensor: si7021 Temperature and Humidity Sensor for the LumiMonitor
- Database will store the temperature and humidity readings at regular intervals
- User can read this data from the mobile device
- With baby surveillance in mind, the sensor is used to monitor the temperature and humidity of the baby room to ensure that the room is comfortable for infants

## Budget

- Total: $247.96CAD; Initially $81.89CAD

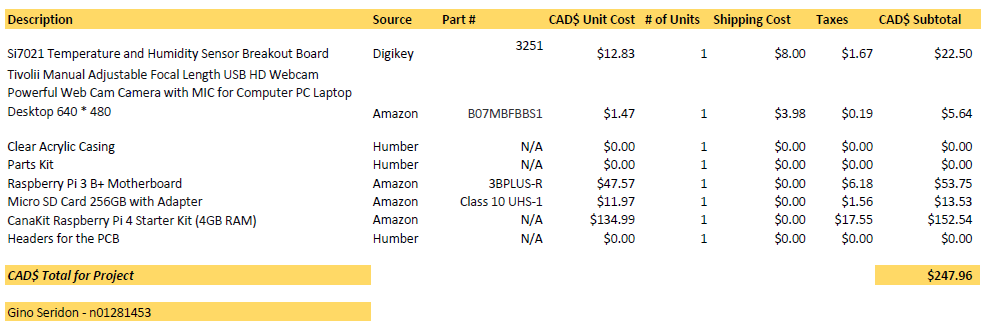
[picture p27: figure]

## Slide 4

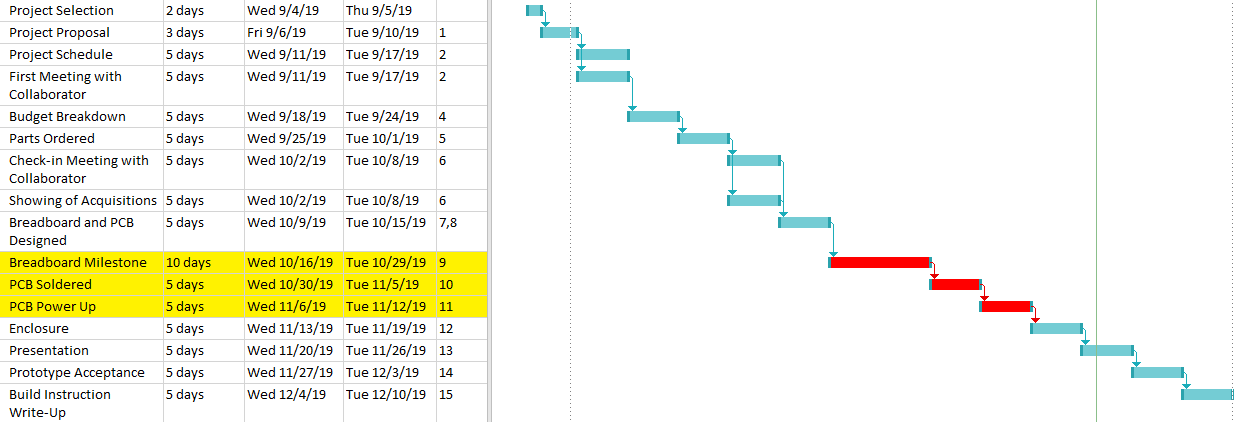
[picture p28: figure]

Problems with the Pi and PCB caused 3 weeks of problems
Previous pi malfunction; purchasing a new RP caused delays
Soldering the PCB incorrectly caused issues when testing

## Sensor’s Enclosure

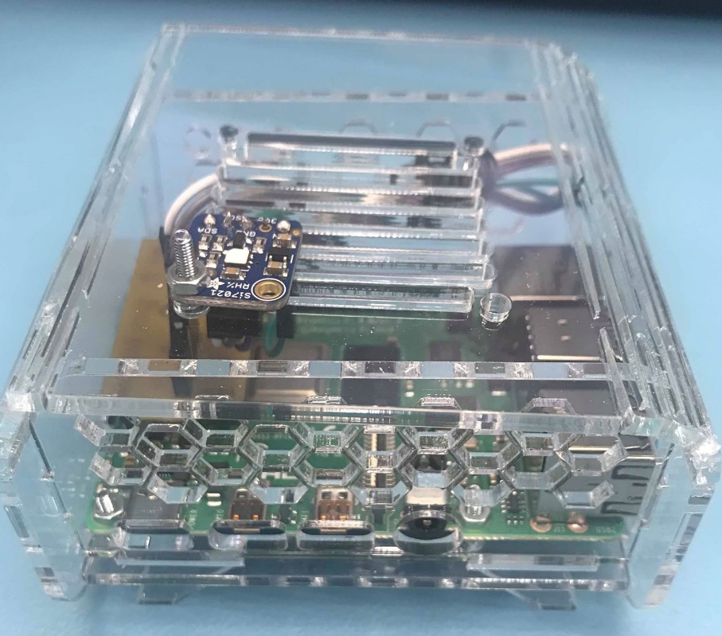
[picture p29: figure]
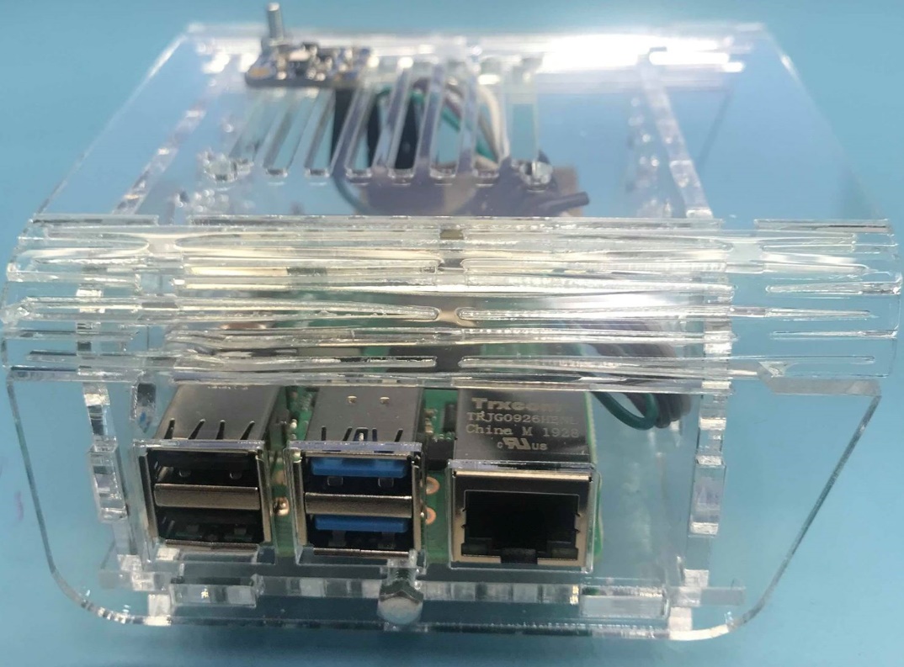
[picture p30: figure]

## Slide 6

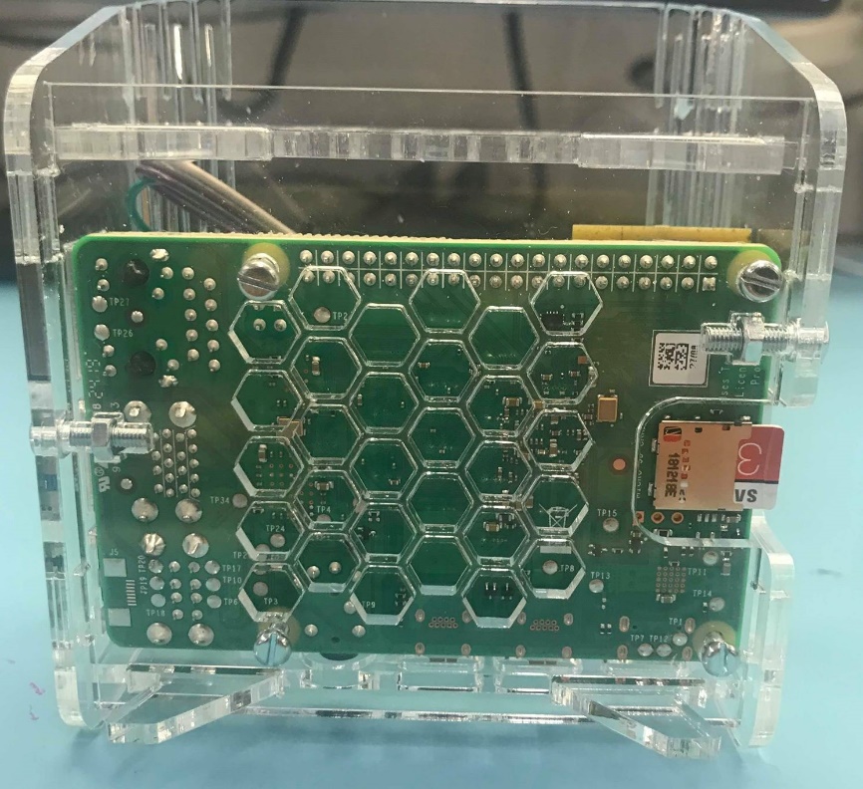
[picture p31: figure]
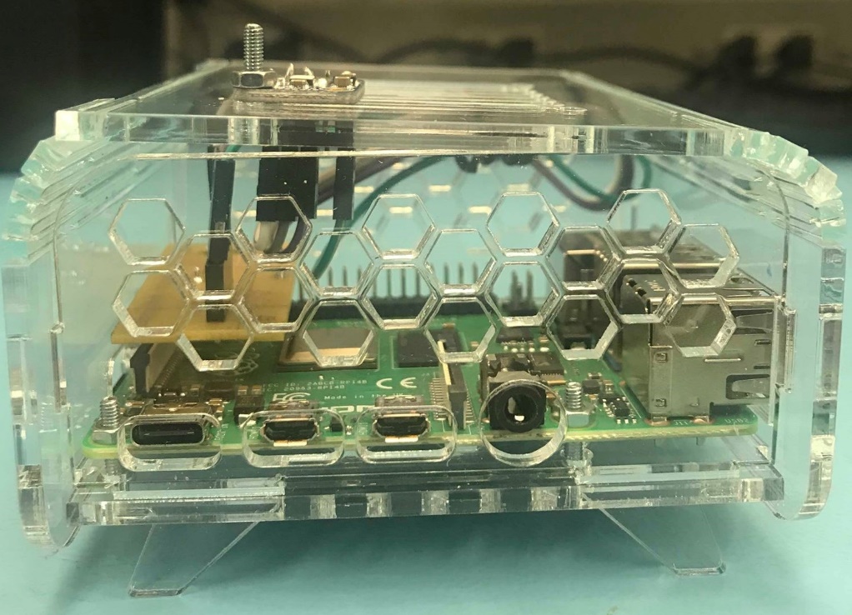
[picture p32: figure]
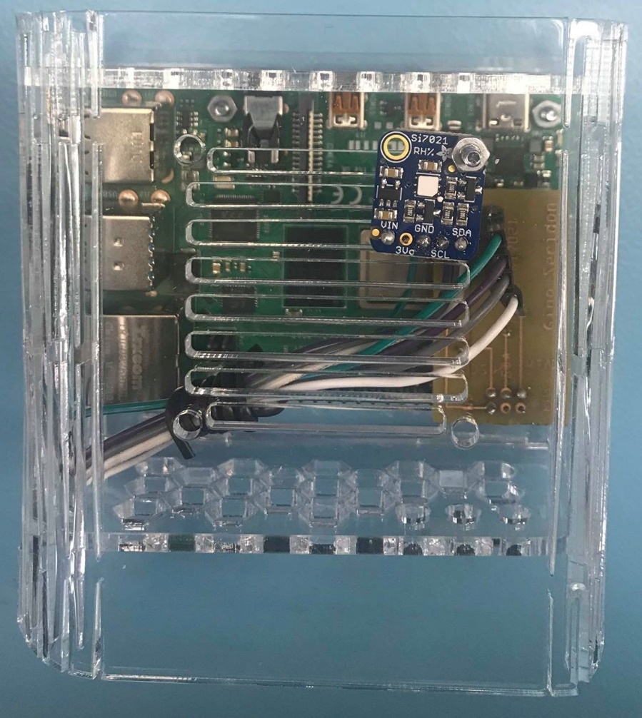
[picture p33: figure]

## Pi’s Address &Functionality

Pi Address: 169.254.33.215

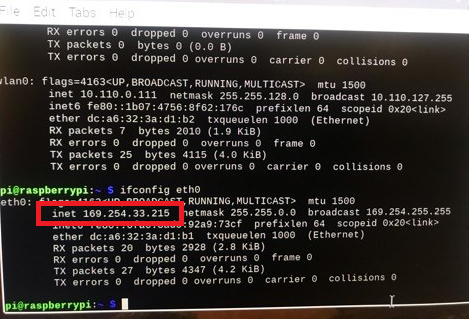
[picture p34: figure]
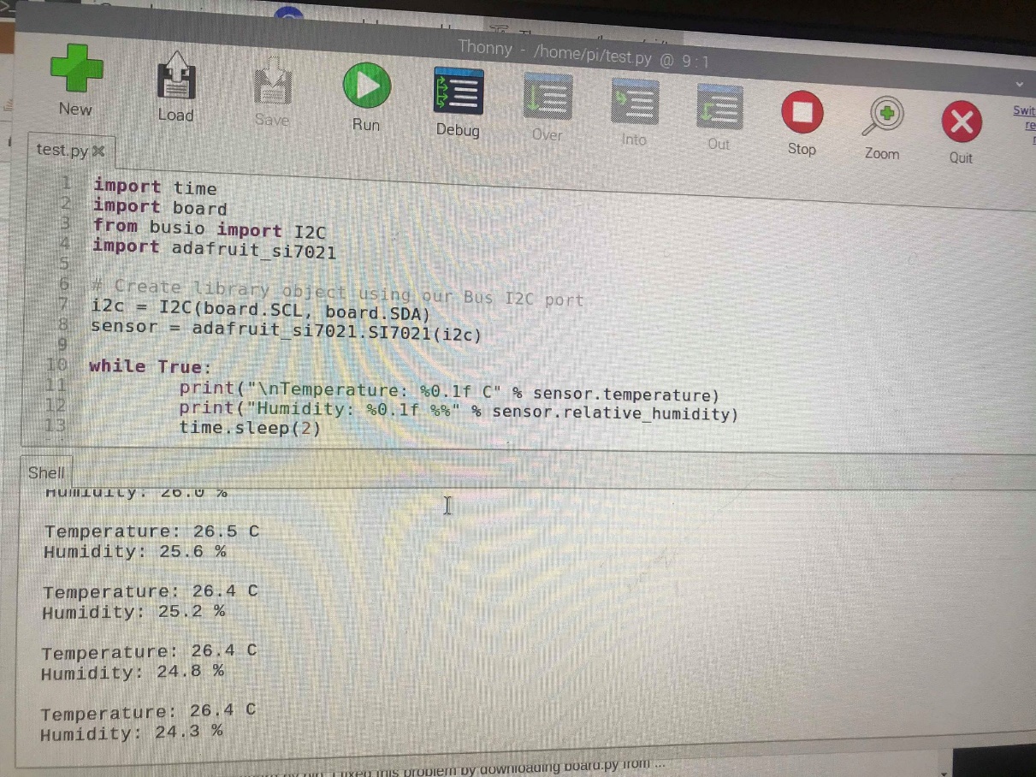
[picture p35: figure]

## Knowledge

- Electric Circuits – TECH101
  - Basic knowledge of circuits (for PCB connections)
  - Measuring voltage
- Technical C – CENG153
  - Introduction to the raspberry pi and its functionalities
  - Understanding how to navigate through a raspberry pi

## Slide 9

Embedded Systems – CENG252
More experience with the raspberry pi
Introduction to version control, used for tracking changes during software development
Software Engineering – CENG216
Design with a purpose and made up of components that work well together
Planning with a budget in mind
Use of a Gantt Chart to create a schedule for the project
Ensuring that the project can be easily implemented along with other software

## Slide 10

Thank you!

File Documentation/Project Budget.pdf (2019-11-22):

Parts for LumiMonitor

Description | Source | Part # | CAD$ Unit Cost # of Units Shipping Cost | Taxes | CAD$ Subtotal Link | Comment
Si7021 Temperature and Humidity Sensor Breakout Board | Digikey | 3251 | $12.83 | 1 | $8.00 | $1.67 | $22.50 https://tinyurl.com/yybwv9qn | The temperature sensor to be used for the PCB; measures humidity and temperature
Tivolii Manual Adjustable Focal Length USB HD Webcam
Powerful Web Cam Camera with MIC for Computer PC Laptop
Desktop 640 * 480 | Amazon | B07MBFBBS1 | $1.47 | 1 | $3.98 | $0.19 | $5.64 https://tinyurl.com/yx8tox44 | Webcam to be used for the LumiMonitor
Clear Acrylic Casing | Humber | N/A | $0.00 | 1 | $0.00 | $0.00 | $0.00 | Enclosure for the sensor. Part of the tuition fee.
Parts Kit | Humber | N/A | $0.00 | 1 | $0.00 | $0.00 | $0.00 | Includes a variety of tools and resources to create the PCB. Already owned.
Raspberry Pi 3 B+ Motherboard | Amazon | 3BPLUS-R | $47.57 | 1 | $0.00 | $6.18 | $53.75 https://tinyurl.com/un746oo | Raspberry Pi, older version. Comes with the motherboard and power cable.
Micro SD Card 256GB with Adapter | Amazon | Class 10 UHS-1 | $11.97 | 1 | $0.00 | $1.56 | $13.53 https://tinyurl.com/r3ddtdk | MicroSD Card for the Raspberry Pi Operating System
CanaKit Raspberry Pi 4 Starter Kit (4GB RAM) | Amazon | N/A | $134.99 | 1 | $0.00 | $17.55 | $152.54 https://tinyurl.com/vg57wxr | Purchased a Raspberry Pi 4 due to malfunctioning Raspberry Pi 3
Headers for the PCB | Humber | N/A | $0.00 | 1 | $0.00 | $0.00 | $0.00 | Headers that are soldered to the PCB
CAD$ Total for Project | | | | | | | $247.96

Gino Seridon - n01281453

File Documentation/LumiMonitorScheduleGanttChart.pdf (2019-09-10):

ID | Task
Mode
| Task Name | Duration | Start | Finish
1 | Project Selection | 2 days | Wed 9/4/19 | Thu 9/5/19
2 | Project Proposal | 3 days | Fri 9/6/19 | Tue 9/10/19
3 | Project Schedule | 5 days | Wed 9/11/19 | Tue 9/17/19
4 | First Meeting with Collaborator | 5 days | Wed 9/11/19 | Tue 9/17/19
5 | Budget Breakdown | 5 days | Wed 9/18/19 | Tue 9/24/19
6 | Parts Ordered | 5 days | Wed 9/25/19 | Tue 10/1/19
7 | Check-in Meeting with Collaborator | 5 days | Wed 10/2/19 | Tue 10/8/19
8 | Showing of Acquisitions | 5 days | Wed 10/2/19 | Tue 10/8/19
9 | Breadboard and PCB Designed | 5 days | Wed 10/9/19 | Tue 10/15/19
10 | Breadboard Milestone | 10 days | Wed 10/16/19 | Tue 10/29/19
11 | PCB Soldered | 5 days | Wed 10/30/19 | Tue 11/5/19
12 | PCB Power Up | 5 days | Wed 11/6/19 | Tue 11/12/19
13 | Enclosure | 5 days | Wed 11/13/19 | Tue 11/19/19
14 | Presentation | 5 days | Wed 11/20/19 | Tue 11/26/19
15 | Prototype Acceptance | 5 days | Wed 11/27/19 | Tue 12/3/19
16 | Build Instruction Write-Up | 5 days | Wed 12/4/19 | Tue 12/10/19
30 | 4 | 9 | 14 | 19 | 24 | 29
September 2019 | October 2019

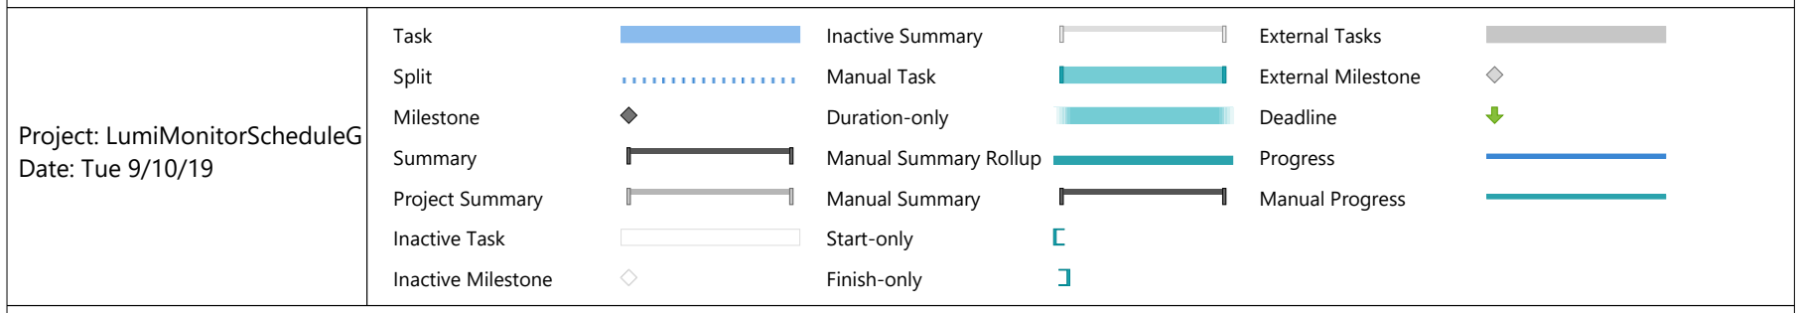
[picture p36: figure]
Task; Split; Milestone; Summary; Project Summary; Inactive Task; Inactive Milestone; Inactive Summary; Manual Task; Duration-only; Manual Summary Rollup; Manual Summary; Start-only; Finish-only; External Tasks; External Milestone; Deadline; Progress; Manual Progress; Project: LumiMonitorScheduleG Date: Tue 9/10/19

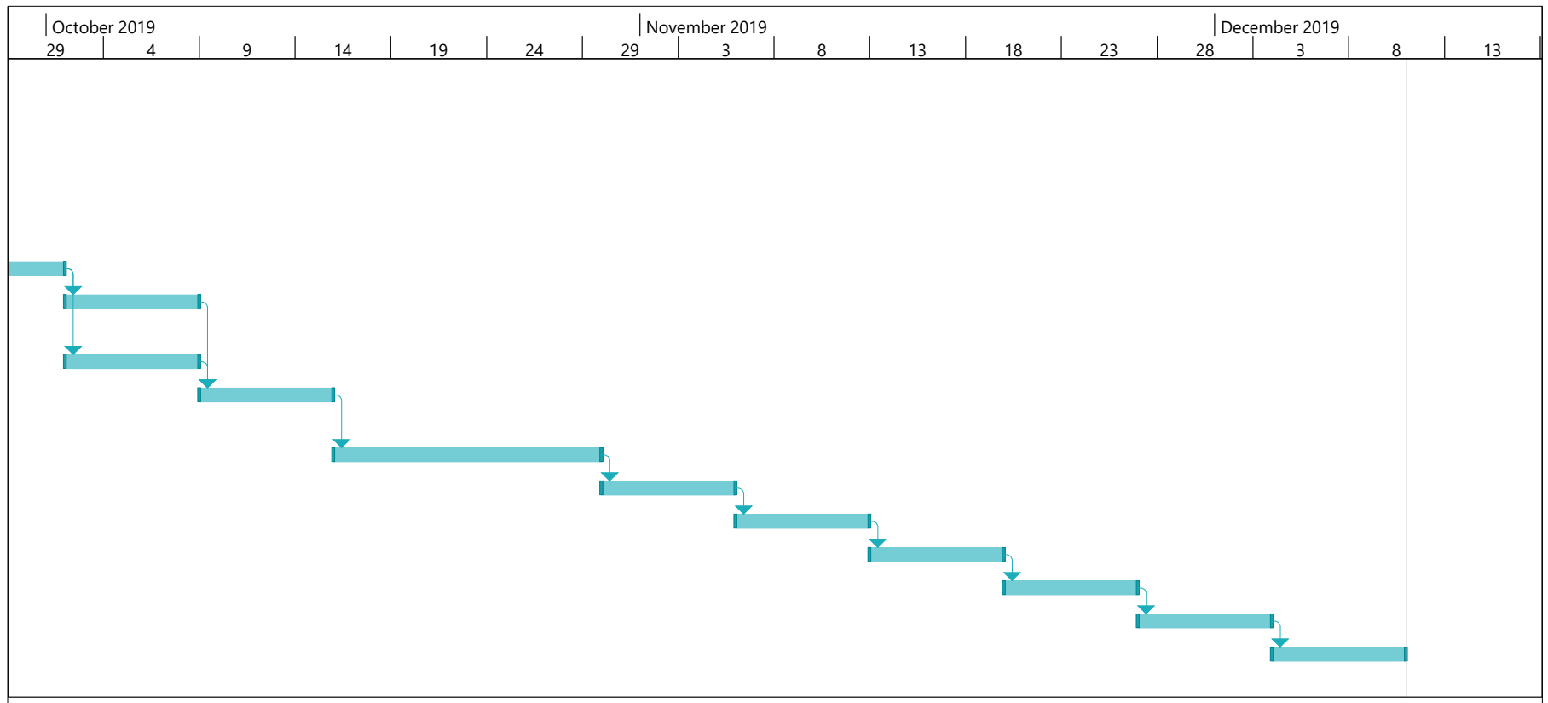
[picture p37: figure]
October 2019; November 2019; December 2019

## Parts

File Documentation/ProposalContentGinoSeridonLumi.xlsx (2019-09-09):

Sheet: DataEntry
Submission Date | 2019-09-10
Project Name | Lumi Monitor
Student Names | Gino Seridon, Kyle Voduris, Harsimran Saini
Project repository | https://github.com/gseridon/LumiMonitor
SensorsEffectors choices | Motion Detector, Light Sensor, Microphone, LED Lights, Audio Speakers
The database will store | Information about active/inactive times and duration, user login to account for personal customization of Lumi, audio recordings and music storage
The mobile device functionality will include | Ability to adjust and customize the monitor's lights, activation based on surroundings (motion/light/sound detection), viewing data infant data on times of sleep (and duration), as well as the played audio (lullabies) and its volume.
I will be collaborating with the following company/department | Humber College School of Media Studies and Information Technology
My group in the winter semester will include | Kyle Voduris, Harsimran Saini
50 word problem statement | Designing a baby monitor with a working lamp and audio input and output system with respective sensors. This device should allow the newborn's parents to better monitor their child, and alert the parents during the child's times of need via an associated mobile device.
100 words of background | With baby surveillance in mind, Lumi is designed to provide a customizable nightlight using an adjustable LED, as well as a working audio feed to input the surrounding sounds and output lullabies. The device can play music or an audio feed directly from a mobile device. The volume and audio type can be adjusted. This device will be able to record times when the child is awake, as well as times of sleep.
Current product APA citation | Pampers. (n.d.). Lumi by Pampers. Retrieved from https://www.pampers.com/lumibypampers?gclid=EAIaIQobChMIy-7Mypa65AIVFLbICh3S-A2PEAAYASAAEgJy4vD_BwE
Existing research IEEE paper APA citation | Jabbar, W., Hamid, S., Almohammedi, A., Ramli, R., & Ali, M. (2019). IoT-BBMS: Internet of things-based baby monitoring system for smart cradle. IEEE, 7, 1-15. doi: 10.1109/ACCESS.2019.2928481
Brief description of planned purchases | Raspberry Pi, Speakers, Microphone, RBG LED Strip, Motion/Light Detector
Solution description | The raspberry pi will have the processor. The LED and speakers will be activated by both the motion sensors and the light sensors. The presence of motion, light and sound near the monitor will determine the activity of the LED and the speakers. The LED will act as a customizable baby lamp that will adjust based on motions near the monitor. A microphone is used to pick up sounds near the baby and can activate the speaker to play music or play audio feed from a connected mobile device. We plan to improve on the design and allow more freedom with customization and convenience for new parents.

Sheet: DataBase
Submission Date | Project Name | Student Names | Project repository | SensorsEffectors choices | The database will store | The mobile device functionality will include | I will be collaborating with the following company/department | My group in the winter semester will include | 50 word problem statement | 100 words of background | Current product APA citation | Existing research IEEE paper APA citation | Brief description of planned purchases | Solution description
2019-09-10 | Lumi Monitor | Gino Seridon, Kyle Voduris, Harsimran Saini | https://github.com/gseridon/LumiMonitor | Motion Detector, Light Sensor, Microphone, LED Lights, Audio Speakers | Information about active/inactive times and duration, user login to account for personal customization of Lumi, audio recordings and music storage | Ability to adjust and customize the monitor's lights, activation based on surroundings (motion/light/sound detection), viewing data infant data on times of sleep (and duration), as well as the played audio (lullabies) and its volume. | Humber College School of Media Studies and Information Technology | Kyle Voduris, Harsimran Saini | Designing a baby monitor with a working lamp and audio input and output system with respective sensors. This device should allow the newborn's parents to better monitor their child, and alert the parents during the child's times of need via an associated mobile device. | With baby surveillance in mind, Lumi is designed to provide a customizable nightlight using an adjustable LED, as well as a working audio feed to input the surrounding sounds and output lullabies. The device can play music or an audio feed directly from a mobile device. The volume and audio type can be adjusted. This device will be able to record times when the child is awake, as well as times of sleep. | Pampers. (n.d.). Lumi by Pampers. Retrieved from https://www.pampers.com/lumibypampers?gclid=EAIaIQobChMIy-7Mypa65AIVFLbICh3S-A2PEAAYASAAEgJy4vD_BwE | Jabbar, W., Hamid, S., Almohammedi, A., Ramli, R., & Ali, M. (2019). IoT-BBMS: Internet of things-based baby monitoring system for smart cradle. IEEE, 7, 1-15. doi: 10.1109/ACCESS.2019.2928481 | Raspberry Pi, Speakers, Microphone, RBG LED Strip, Motion/Light Detector | The raspberry pi will have the processor. The LED and speakers will be activated by both the motion sensors and the light sensors. The presence of motion, light and sound near the monitor will determine the activity of the LED and the speakers. The LED will act as a customizable baby lamp that will adjust based on motions near the monitor. A microphone is used to pick up sounds near the baby and can activate the speaker to play music or play audio feed from a connected mobile device. We plan to improve on the design and allow more freedom with customization and convenience for new parents.

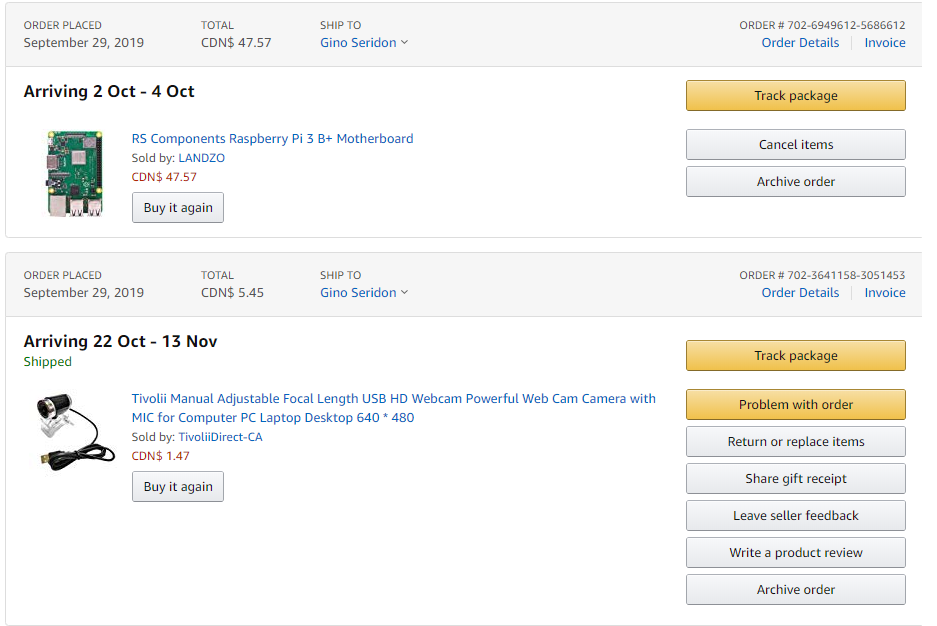
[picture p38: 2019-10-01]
Images/AmazonOrder.png

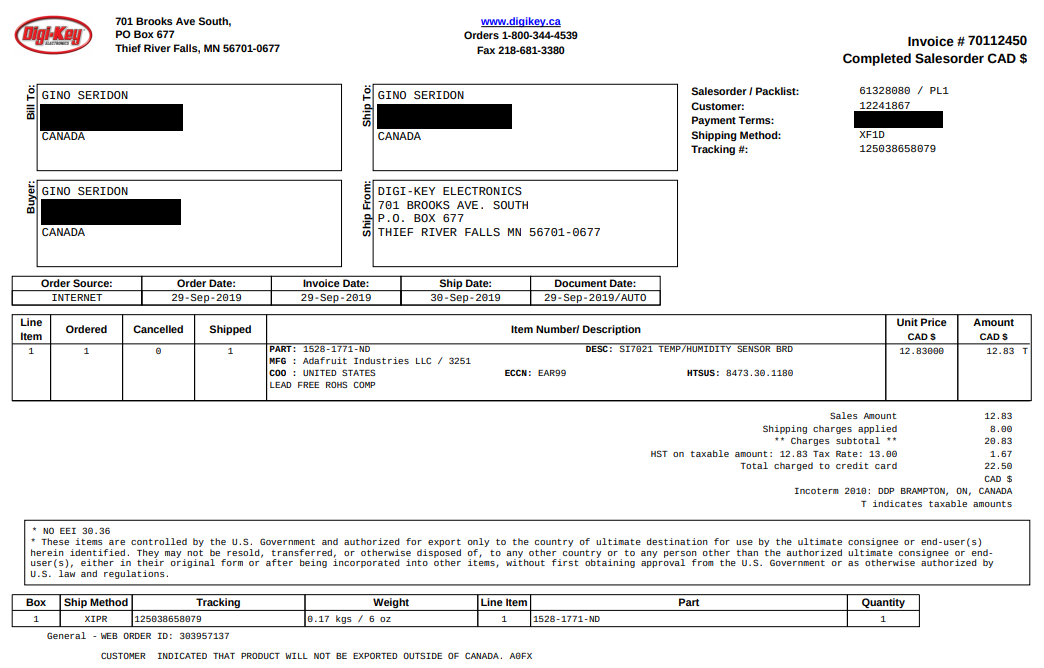
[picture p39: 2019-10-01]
Images/DigikeyOrder.png

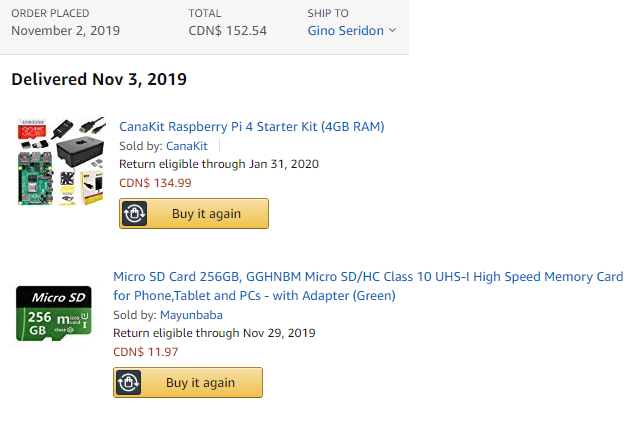
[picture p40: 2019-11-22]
Images/AmazonOrder2.png

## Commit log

2019-09-09 Add files via upload
    Uploading repository documentation.
    [ProposalContentGinoSeridonLumi.xlsx]
2019-09-09 Create PCBFiles
